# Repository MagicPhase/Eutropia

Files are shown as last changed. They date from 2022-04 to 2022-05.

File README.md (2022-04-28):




# Eutropia
Open Source ESP32 Multi Sensor Platform. 

This PCB design offers numerous optional features and configurations built around the ESP-WROOM-32 30PIN module. The footprint is designed to match with the Nextion 2.8" Smart Displays. The primary desgin goal was to have a wide range of sensor inputs coupled with high current outputs to fit an equally wide range of applications. This includes a reasonably small footprint for portability and battery operation.

## Feature list:

- 2 High Power Outputs  
- 2 Optocouple Outputs  
- 2 Medium Power Outputs  
- Current/Voltage sensing  
- RTC Clock  
- Low Pressure Sensor  
- Accelerometer/Gyro  
- Humidity Sensor  
- Water Ingress Sensor  
- 1 Input/Output Port  
- 1 Input Port (multifuntion) 
- 2 Neo Pixel LEDs  
- Mounting Holes For Nextion 2.8" Serial Display

## ESP32 I/O configuration:

>D39(I) Attached to INA3221 programable warning for over current monitor.  
>D36(I) Labelled (AUX1) pin is attached to 3-pin header for general use as default. 
JP3 can connect the MPU (INT) pin for auto calibration. JP1 can connect to water ingress sensor. Only one function can be used.  
>D35(I) Input for thermal sensor near CH2 FET.  
>D34(I) Input for thermal sensor near CH' FET.  
>D33(IO) Output PWM for CH2 FET via driver (MIC4127 CHB).  
>D32(IO) Output PWM for CH1 FET via driver (MIC4127 CHA).  
>D23(IO) Labelled (AUX2) pint is attached to 3-pin JST header for general purpose.  
>D22(IO) I2C SCL pin.  
>D21(IO) I2C SDA pin.  
>D17(IO) Serial TX2 pin.  
>D16(IO) Serial RX2 pin.  
>D19(IO) Output PWM for CH4 FET.  
>D18(IO) Output PWM for CH3 FET.  
>D5(IO) Attached to 2 JTS headers with 4.7k pullup resistor. These are intended for DS18D20 temp sensors.  
>D1(IO) Attached to the input of the Neo Pixel (SK6805). This pin is also used by the Serial port during programing.  
All other IO pins are left unattached as to not interfere during WiFi operations.  

## Board Headers:
>CH1 High Output XT30 Female  
>CH2 High Output XT30 Female  
>CH3 Low Output JST_PH_B2B-PH-K_1x02_P2.00mm  
>CH4 Low Output JST_PH_B2B-PH-K_1x02_P2.00mm  
>HEADER1 I2C PULLUP PinHeader_2x02_P2.00mm  
>HEADER2 VIN/5V SELECT PinHeader_2x03_P2.00mm  
>HEADER3 FET/OPTO SELECT PinHeader_2x03_P2.00mm  
>HEADER4 I2C HEADER	PinHeader_1x04_P2.00mm  
>HEADER5 Serial2  PinHeader_1x04_P2.50mm  

FRONT
BACK

Two High Power FET's capable of >50watt output. These channels have current/voltage monitoring, thermal monitoring, and safety fuses. These outputs are selectable with two optocoupler drivers via a jumper header.
  
Two Medium power FET's capable of 10watt output. These channels Have selectable input voltages of either VIN(12-24) or 5V.
  
Three channels of current/voltage monitoring. Monitoring is split between the 2 high current channels and the remainder of all devices on the board. Total power usage is a sum of all three channels.
  
RTC clock is used for basic time keeping and has battery backup.
  
The low pressure sensor is an absolute pressure type and designed for low pressure monitoring of <10psi. The sensor has a metal port.
  
Accelerometer/gyro optional port is compatible with the MPU-6050 board. It is also possible to fit the MPU-9250, however the board will protrude from the top approximately 5mm and the two lower pins should be clipped. There is also a footprint on the main board for an MPU-6050 chip with selectable I2C address. If the chip is present on the main board, do not populate with an expansion board!
  
One input/output via a three pin JST(2mm pitch) header.
  
One input only pin via a three pin JST(2mm pitch) header. This input is a shared input. See D36 pin configuration.

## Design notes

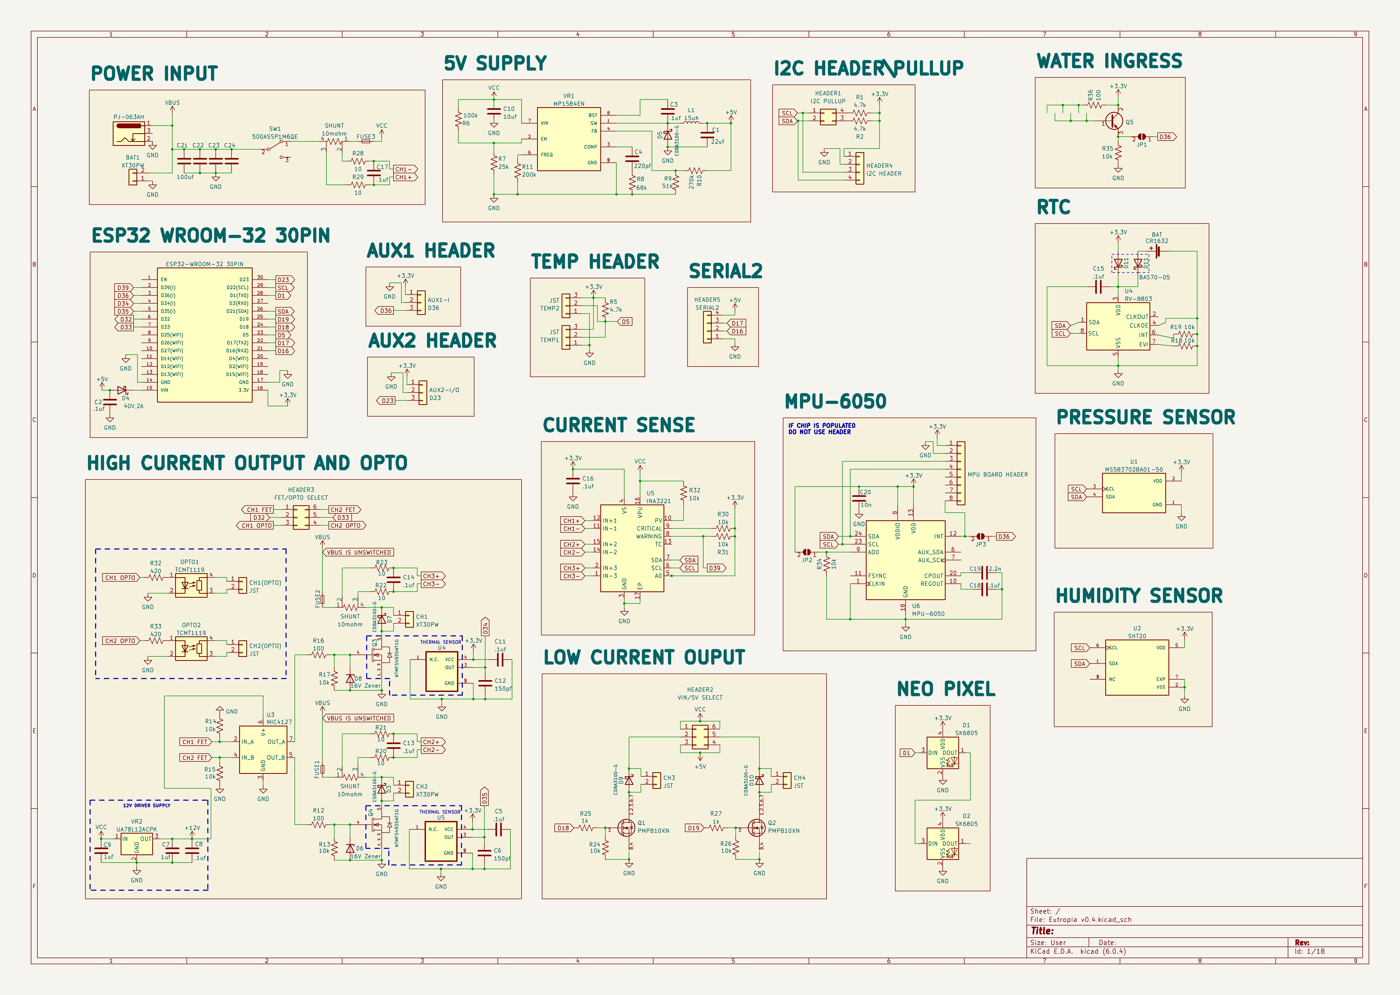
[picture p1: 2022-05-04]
Eutropia v0.4 Schematic.jpg

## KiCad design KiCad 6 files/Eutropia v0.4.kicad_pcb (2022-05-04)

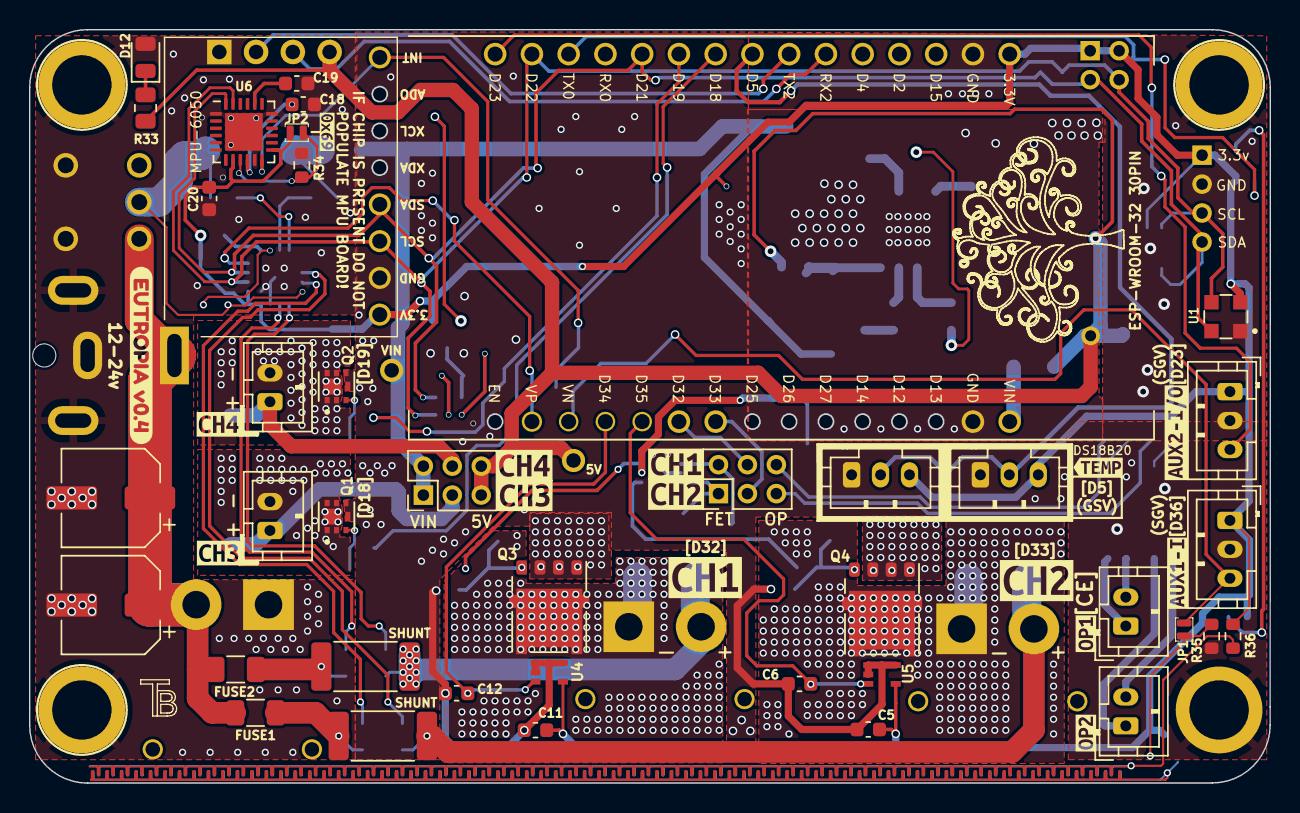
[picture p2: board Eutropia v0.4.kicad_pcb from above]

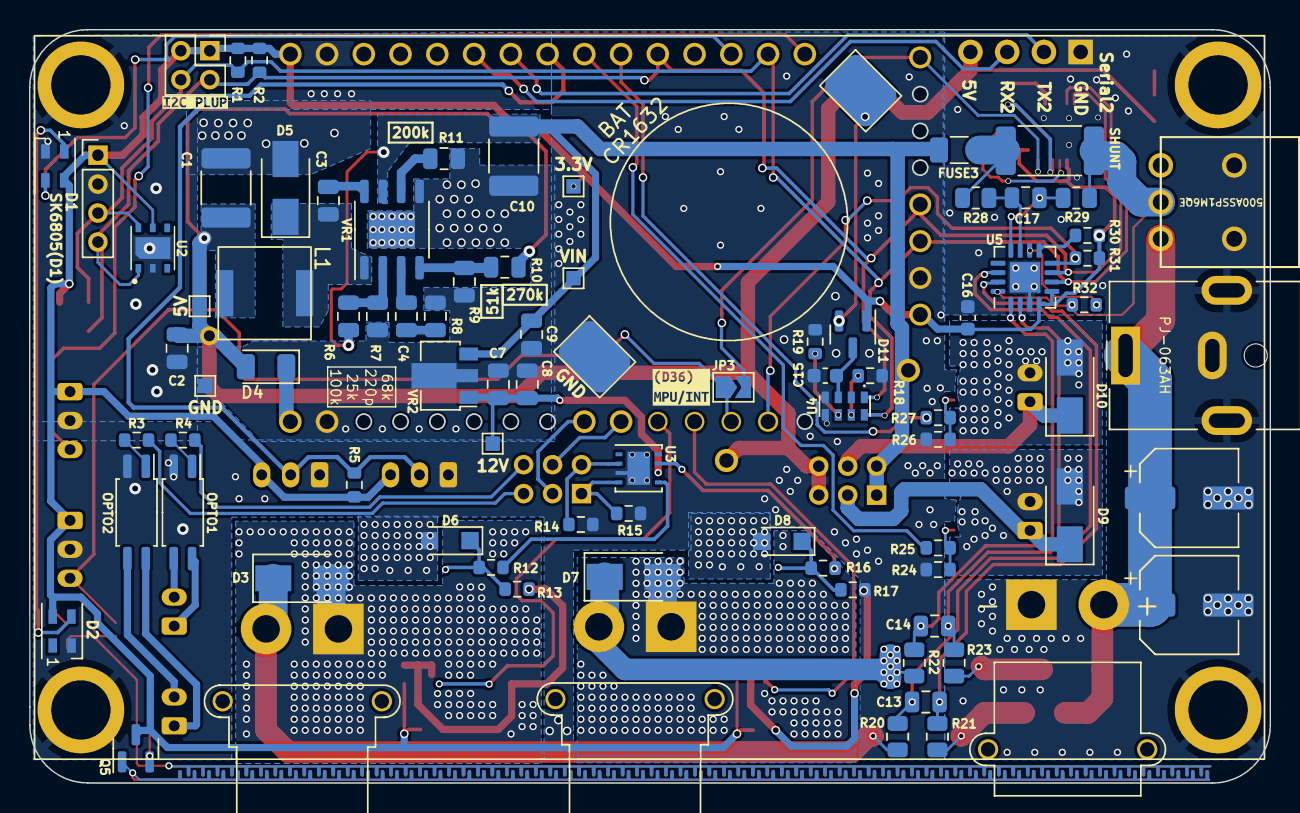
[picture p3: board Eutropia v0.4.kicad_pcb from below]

Board: 2 copper layers, 85.7 x 52.1 mm, 144 parts (88 on the bottom side), 39 nets.

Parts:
BAT: CR1632; CR1632-BU1632SM
BAT1: AMASS_XT30PW-M_1x02_P2.50mm_Horizontal
C1: 22uf; C_1812_4532Metric
C2, C3, C8, C13, C14, C17: .1uf; C_0805_2012Metric
C4: 220pf; C_0805_2012Metric
C5, C11, C15, C16, C18: .1uf; C_0603_1608Metric
C6, C12: 150p; C_0603_1608Metric
C7: 10uf; C_0805_2012Metric
C9: 1uf; C_0805_2012Metric
C10: 10uf; C_1812_4532Metric
C19: 2.2n; C_0603_1608Metric
C20: 10n; C_0603_1608Metric
C21, C22, C23, C24: 100uf; CP_Elec_6.3x7.7
CH1, CH2: AMASS_XT30PW-F_1x02_P2.50mm_Horizontal
CH1(OPTO), CH2(OPTO), CH3, CH4: JST_PH_B2B-PH-K_1x02_P2.00mm_Vertical
D1, D2: SK6805; LED_SK6805_PLCC4_2.4x2.7mm_P1.3mm
D3, D5, D7, D9, D10: CDBA3100-G; D_SMA
D4: SD1206T040S2R0; D_1206_3216Metric
D6, D8: Nexperia_CFP3_SOD-123W
D11: BAS70-05; SOT-23
D12: LED 20ma; LED_0805_2012Metric
ESP-WROOM-32 30PIN: ESP-WROOM-32 30PIN; MODULE_ESP32-DEVKITC-32D V2
FUSE1, FUSE2, FUSE3: Fuse_1206_3216Metric
HEADER1: I2C PULLUP; PinHeader_2x02_P2.00mm_Vertical
HEADER2: VIN/5V SELECT; PinHeader_2x03_P2.00mm_Vertical
HEADER3: FET/OPTO SELECT; PinHeader_2x03_P2.00mm_Vertical
HEADER4: I2C HEADER; PinHeader_1x04_P2.00mm_Vertical
HEADER5: Serial2; PinHeader_1x04_P2.54mm_Horizontal
I/36: JST_PH_B3B-PH-K_1x03_P2.00mm_Vertical
IO/23: JST_PH_B3B-PH-K_1x03_P2.00mm_Vertical
JP1: Water Ingress; Solder Jumper 1mm
JP2: 0x69 MPU I2C; Solder Jumper 1mm
JP3: MPU INT to D36; SolderJumper-2_P1.3mm_Open_TrianglePad1.0x1.5mm
L1: 15uh inductor
MPU: MPU-6050 accelerometer
Nextion 2.8: Nextion 2.8
OPTO1, OPTO2: TCMT1119; SOP-4_4.4x2.6mm_P1.27mm
PJ-063AH: BarrelJack_CUI_PJ-063AH_Horizontal
Q1, Q2: PMPB10XNX; TRANS_PMPB16EPX
Q3, Q4: NTMFS4935NT1G; ONSemi_SO-8FL_488AA
Q5: MMBT2222A; SOT-23
R1, R2, R5: 4.7k; R_0603_1608Metric
R3, R4: 420; R_0603_1608Metric
R6: 100k; C_0805_2012Metric
R7: 25k; C_0805_2012Metric
R8: 68k; C_0805_2012Metric
R9: 51k; C_0805_2012Metric
R10: 270k; C_0805_2012Metric
R11: 200k; C_0805_2012Metric
R12, R16: 50; R_0603_1608Metric
R13, R14, R15, R17, R18, R19, R24, R26, R30, R31, R32, R34, R35: 10k; R_0603_1608Metric
R20, R21, R22, R23, R28, R29: 10; R_0805_2012Metric
R25, R27: 500; R_0603_1608Metric
R33: 150; R_0805_2012Metric
R36: 100; R_0603_1608Metric
SHUNT: 10mohm; R_2512_6332Metric_Pad1.40x3.35mm_HandSolder
SHUNT#2, SHUNT#3: 10mohm; R_2512_6332Metric_Pad1.40x3.35mm_HandSolder
SW1: 500ASSP1M6QE; d22ce012-2fd7-45db-96b5-83cda7ebcca8
TEMP1, TEMP2: JST_PH_B3B-PH-K_1x03_P2.00mm_Vertical
TP1: 5V; Standard Pad TH
TP2: GND; TestPoint_Pad_1.0x1.0mm
TP3: 5V; TestPoint_Pad_1.0x1.0mm
TP4: 12V; TestPoint_Pad_1.0x1.0mm
TP5: VIN; TestPoint_Pad_1.0x1.0mm
TP6: 3.3V; TestPoint_Pad_1.0x1.0mm
U1: MS583702BA01
U2: XDCR_SHT20
U3: MIC4127; MLF-8-1EP_3x3mm_P0.65mm_EP1.55x2.3mm
U4, U5: MAX6613MXK; SC70-5
U4#2: RV-8803
U5#2: INA3221; Texas_RGV_S-PVQFN-N16_EP2.1x2.1mm
U6: MPU-6050; QFN-24-1EP_4x4mm_P0.5mm_EP2.6x2.6mm
VR1: MP1584EN; SOIC-8-1EP_3.9x4.9mm_P1.27mm_EP2.514x3.2mm
VR2: SOT-89-3
kibuzzard-625BD4CB: G***; kibuzzard-625BD4CB
kibuzzard-625BD4D5: G***; kibuzzard-625BD4D5
kibuzzard-625BD9A7: G***; kibuzzard-625BD9A7
kibuzzard-625BD9B1: G***; kibuzzard-625BD9B1
kibuzzard-625BD52D: G***; kibuzzard-625BD52D
kibuzzard-625BD60C: G***; kibuzzard-625BD60C
kibuzzard-625BD91F: G***; kibuzzard-625BD91F
kibuzzard-625BD92B: G***; kibuzzard-625BD92B
kibuzzard-625BD538: G***; kibuzzard-625BD538
kibuzzard-625BD597: G***; kibuzzard-625BD597
kibuzzard-625BDEC7: G***; kibuzzard-625BDEC7
kibuzzard-625BDEDE: G***; kibuzzard-625BDEDE
kibuzzard-625FE1CF: G***; kibuzzard-625FE1CF
kibuzzard-625FE15C: G***; kibuzzard-625FE15C
kibuzzard-625FE593: G***; kibuzzard-625FE593
kibuzzard-6264A044: G***; kibuzzard-6264A044
kibuzzard-62649B95: G***; kibuzzard-62649B95

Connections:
3.3V: C5.2, C11.2, C16.2, C20.2, D1.V, D2.V, D11.A, ESP-WROOM-32 30PIN.3.3V, HEADER1.1, HEADER1.3, HEADER4.1, I/36.1, IO/23.1, JP2.2, MPU.1, Q5.C, R1.1, R2.1, R5.2, R30.1, R31.1, R36.2, TEMP1.3, TEMP2.3, TP6.1, U1.V, U2.VDD, U4.VCC, U5.VCC, U5#2.A0, U5#2.VS, U6.VDD-13, U6.VLOGIC-8
5V: C1.2, C2.2, D4.2, HEADER2.5, HEADER2.6, HEADER5.4, L1.5V, R10.2, R33.2, TP1.1, TP3.1
12V: C7.2, C8.2, TP4.1, U3.Vs, VR2.Vo
BAT: BAT.1, D11.2
CH1+: CH1.2, D7.1, R22.1, SHUNT#2.2
D1: D1.IN, ESP-WROOM-32 30PIN.TX0
D5: ESP-WROOM-32 30PIN.D5, R5.1, TEMP1.2, TEMP2.2
D18: ESP-WROOM-32 30PIN.D18, R25.2
D19: ESP-WROOM-32 30PIN.D19, R27.2
D23: ESP-WROOM-32 30PIN.D23, IO/23.3
D32: ESP-WROOM-32 30PIN.D32, HEADER3.4, HEADER3.6, R4.2, R16.1, U3.OUTA
D33: ESP-WROOM-32 30PIN.D33, HEADER3.3, HEADER3.5, R3.2, R12.1, U3.OUTB
D34: C12.2, ESP-WROOM-32 30PIN.D34(I), U4.OUT
D35: C6.2, ESP-WROOM-32 30PIN.D35(I), U5.OUT
D36: ESP-WROOM-32 30PIN.VN(I), I/36.3, JP1.1, JP3.1, JP3.2, MPU.8, U6.INT-12
D39: ESP-WROOM-32 30PIN.VP(I), R31.2, U5#2.WARN
DRAIN: CH1.1, CH2.1, CH3.2, CH4.2, D3.2, D7.2, D9.2, D10.2, Q1.D, Q2.D, Q3.D, Q4.D
EVI: R18.1, U4#2.EVI
GND: BAT1.1, C1.1, C2.1, C5.1, C6.1, C7.1, C8.1, C9.2, C10.2, C11.1, C12.1, C15.1, C16.1, C18.1, C19.1, C20.1, C21.2, C22.2, C23.2, C24.2, D1.GND, D2.GND, D5.2, D6.2, D8.2, D12.2, ESP-WROOM-32 30PIN.GND, HEADER4.2, HEADER5.1, I/36.2, IO/23.2, MPU.2, Nextion 2.8.1, OPTO1.C, OPTO2.C, PJ-063AH.2, PJ-063AH.MP, Q1.S, Q2.S, Q3.S, Q4.S, R7.2, R8.1, R9.2, R11.2, R13.2, R14.2, R15.2, R17.2, R18.2, R19.1, R24.2, R26.2, R34.2, R35.1, SW1.1, TEMP1.1, TEMP2.1, TP2.1, U1.G, U2.7, U2.GND, U3.GND, U4.G, U4.NC, U4#2.CLKOE, U4#2.Vss, U5.G, U5.NC, U5#2.17, U5#2.GND, U6.25, U6.CLKIN-1, U6.FSYNC-11, U6.GND-18, VR1.5, VR1.9, VR2.G
IN+1: C17.2, R29.2, U5#2.IN+1
IN+2: C13.2, R21.2, U5#2.IN+2
IN+3: C14.2, R23.2, U5#2.IN+3
IN-1: C17.1, R28.2, U5#2.IN-1
IN-2: C13.1, R20.2, U5#2.IN-2
IN-3: C14.1, R22.2, U5#2.IN-3
INA: HEADER3.2, R14.1, U3.INA
INB: HEADER3.1, R15.1, U3.INB
INT: R19.2, U4#2.INT
PV: R32.2, U5#2.PV
RX2: ESP-WROOM-32 30PIN.RX2, HEADER5.3
SCL: ESP-WROOM-32 30PIN.D22 SCL, HEADER1.4, HEADER4.3, MPU.3, R1.2, U1.SCL, U2.SCL, U4#2.SCL, U5#2.SCL, U6.SCL-23
SDA: ESP-WROOM-32 30PIN.D21 SDA, HEADER1.2, HEADER4.4, MPU.4, R2.2, U1.SDA, U2.SDA, U4#2.SDA, U5#2.SDA, U6.SDA-24
SW: C3.2, D5.1, L1.2, VR1.SW
TX2: ESP-WROOM-32 30PIN.TX2, HEADER5.2
VDD: C15.2, D11.C, U4#2.Vdd
VIN: C9.1, C10.1, FUSE3.1, FUSE3.2, HEADER2.1, HEADER2.2, R6.2, R28.1, SHUNT#3.1, TP5.1, VR1.7, VR2.Vi
VIN-NS: BAT1.2, C21.1, C22.1, C23.1, C24.1, FUSE1.1, FUSE2.1, PJ-063AH.1, SW1.2
VPU: R29.1, R32.1, SHUNT#3.2, SW1.3, U5#2.VPU
ch2+: CH2.2, D3.1, R20.1, SHUNT.2
